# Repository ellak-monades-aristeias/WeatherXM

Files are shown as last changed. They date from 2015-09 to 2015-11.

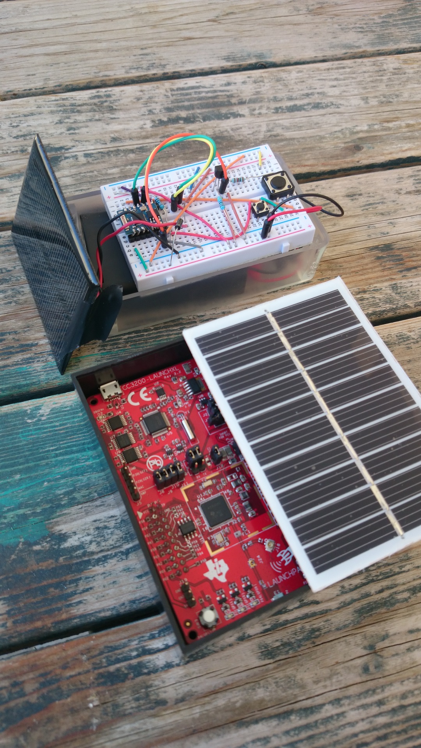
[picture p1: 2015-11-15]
D1-Evaluation/DSC_0020.JPG

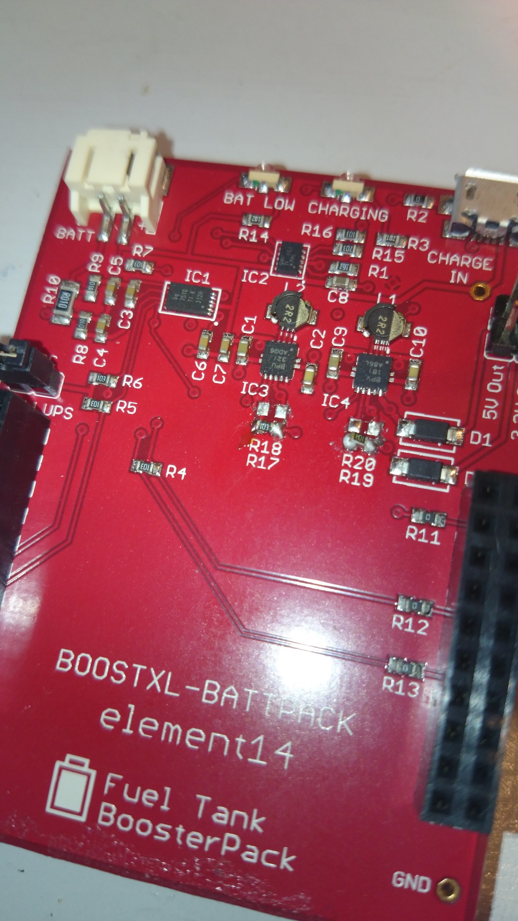
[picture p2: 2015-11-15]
D1-Evaluation/DSC_0005.JPG

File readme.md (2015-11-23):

## Weather ex Machina##

Στόχος του έργου είναι να κατασκευάσουμε ένα πρωτότυπο μετεωρολογικό σταθμό, ανταγωνιστικό προς τους υφιστάμενους ‘παραδοσιακούς’, μεγάλου κόστους μετεωρολογικούς σταθμούς. Ο σταθμός αυτός θα συμβάλλει στην υπέρβαση του προβλήματος διαθεσιμότητας μετεωρολογικών δεδομένων, μέσω της γεωγραφικής ανάπτυξης μεγάλου αριθμού αυτόνομων συνόλων αισθητήρων. Το υλισμικό θα είναι χαμηλού κόστους (<100€), με σύνδεση WiFi σε αστικό περιβάλλον και δυνατότητα για 2G/3G M2M για χρήση σε απομακρυσμένες περιοχές. Όλα τα δεδομένα θα συλλέγονται σε κεντρικό σύστημα σύννεφου (cloud) βασισμένο σε τεχνολογίες big data, ώστε να μπορεί να αποτελέσει μια πρώτη υποδομή για grassroot εφαρμογές smart-city.

**Ακολουθούν τα χαρακτηριστικά στα οποία στοχεύουμε:**
 - Συμπαγής, μικρού μεγέθους, εύκολης τοποθέτησης χωρίς απαραίτητη χρήση ιστού (π.χ. θα μπορούσε να κρέμεται σε ένα παράθυρο/μπαλκόνι/γωνία)
 - Mε αισθητήρες θερμοκρασίας, υγρασίας, ατμοσφαιρικής πίεσης, βροχής και αέρα. Για λόγους κόστους δε θα μετράμε βροχόπτωση, αλλά μόνο ύπαρξη βροχής με αισθητήρες σταγόνας. Αντίστοιχα δε θα μετράμε κατεύθυνση/ένταση αέρα αλλά από την κίνηση του ιδίου του σώματος του κουτιού, εφόσον κρέμεται από ένα κορδόνι, θα καταλαβαίνουμε την άπνοια ή ύπαρξη αέρα 
 - Aυτόνομο ενεργειακά, με την χρήση επαναφορτιζόμενων μπαταριών (LiPo or NiMH) που θα φορτίζουν από ένα μικρο ενσωματωμένο φωτοβολταικο
- Διασύνδεση WiFi και αποστολή δεδομένων μετρήσεων σε server μέσω (HTTP or MQTT)
 - Δυνατότητα ενημέρωσης firmware και φόρτιση μπαταρίας μέσω USB
 - Φιλικό προς DIY κατασκευαστές, συμβατό με Arduino  λογισμικό και έτοιμους αισθητήρες / modules / breakout boards
 - Δυνατότητα λειτουργίας από παραδοσιακό παραλληλεπίπεδο πλαστικό κουτί, μελέτη/προετοιμασία για περίβλημα/κουτί 3D εκτύπωσης, για οταν τα ηλεκτρονικά θα είναι σε custom PCB
 - Δυνατότητα over the Air firmware update
 - Δυνατότητα προσθήκης module για GPS/GALILEO, 3G with M2M Sim, Bluetooth
 - Δυνατότητα σύνδεσης εσωτερικής μονάδας με οθόνη για άμεση εμφάνιση των μετρήσεων

Πιο αναλυτικά οι εργασίες για αυτή την αρχική φάση του έργου είναι:

 **1. Αξιολόγηση υποψήφιου υλισμικού με υλοποίηση ελάχιστου συνδεδεμένου συστήματος (“hello IoT world” prototype)**
Έχουμε εντοπίσει αρκετές πλατφόρμες IoT με (σχεδόν) έτοιμα modules αισθητήρων, οι οποίες είναι συμβατές με arduino και φιλικές για prototyping. 

 - [TI CC3200](<https://github.com/ellak-monades-aristeias/WeatherXM/wiki/cc3200>)
 - [Spark/Particle Core](<https://github.com/ellak-monades-aristeias/WeatherXM/wiki/particle-core>)
 - [ESP8266 standalone](<https://github.com/ellak-monades-aristeias/WeatherXM/wiki/esp8266-standalone>)
 - [Atmega328 & NRF24 & ESP8266](<https://github.com/ellak-monades-aristeias/WeatherXM/wiki/ArduinoProMini_3.3.v-NRF24>)
 
Είναι εξαιρετικά δύσκολο να καταλήξει κανείς στην επιλογή μιας IoT πλατφόρμας χωρίς σε  βάθος προηγούμενη εμπειρία με τη συγκεκριμένη οικογένεια hardware/software. Οι εξελίξεις ομως στο IoT είναι τόσο ραγδαίες που πολλές πλατφόρμες πρώτο-εμφανίστηκαν στην αγορά μόλις πριν λίγους μήνες.  Για το λόγο αυτό και ακολουθώντας λογική agile, αναπτύσσουμε ένα ελάχιστο, αλλά ολοκληρωμένο σύστημα στις παραπάνω πλατφόρμες ώστε να τις αξιολογίσουμε. Το “hello IoT world” prototype είναι ένα wifi-θερμόμετρο με cloud backend (π.χ. thingspeak). Στόχος σε αυτή τη φάση είναι η αξιολόγηση και σύγκριση των πλεονεκτημάτων/μειονεκτημάτων της κάθε πλατφόρμας και η καταγραφή των διαφόρων αποτελεσμάτων (π.χ. κατανάλωση) ώστε να επιλέξουμε την ιδανικότερη με την ποια θα προχωρήσουμε. 

**2. Κατασκευή πρωτότυπου hardware**
Σε συνέχεια της αξιολόγησης και επιλογής ιδανικού hardawre, έχουμε προχωρήσουμε με την υλοποίηση των προδιαγραφών του μετεωρολογικού σταθμού, προσθέτοντας τα απαραίτητα περιφερειακά εξαρτήματα και αισθητήρες, πάνω στη βέλτιστη IoT πλατφόρμα (αποτέλεσμα προηγουμένης φάσης). Παράλληλα εμπλουτιζουμε το λογισμικό firmware  (arduino compatible) που θα διαχειρίζεται τα δεδομένα των αισθητήρων (μετεωρολογικά δεδομένα), και τα στέλνει περιοδικά σε κάποιο “ανοιχτό” cloud service  (π.χ. https://thingspeak.com/) 
([Περισσότερα](https://github.com/ellak-monades-aristeias/weatherxm/wiki/WxM-prototype))

**3. Σύνδεση hardware με backend ανοιχτό λογισμικό με δυνατότητα διαχείρισης big data**
Μέσα από προηγούμενες εμπειρίες έχουμε καταλήξει σε μια σειρά από προτεινόμενες τεχνολογίες για την διαχείριση big data όπως: Spring framework, Apache HBASE, Spark, mongoDB, Redis, Solr, etc.  οι οποίες όμως είναι αρκετά συνθέτες στη λειτουργία/εγκατάσταση. Στο opensource (CPAL-1.0) project [sitewhere.org](http://sitewhere.org) καθώς και στο [sentilo.io](http://sentilo.io) υπάρχει ήδη μια πολύ καλή διασύνδεση/integration αυτών των τεχνολογιών, καθώς και δυνατότητά για σύνδεση με arduino compatible hardware, οπότε θα κάνουμε τις απαραίτητες τροποποιήσεις στο firmware και στο server, ώστε να γίνει η σύνδεση του hardware μας με το backend για να μπορούμε να αξιοποιήσουμε τα μετεωρολογικά δεδομένα με διάφορους τρόπους, π.χ. απεικόνιση σε διαδραστικό χάρτη σε πραγματικό χρόνο, γραφήματα με ιστορικά δεδομένα, κτλ. Θα χρησιμοποιήσουμε MQTT ή HTTP πρωτόκολλο για να διευκολύνουμε και μελλοντικές διασυνδέσεις με τρίτα συστήματα ή/και άλλο IoT hardware με στόχο την δημιουργία υποδομής smart-city.
([Περισσότερα](https://github.com/ellak-monades-aristeias/WeatherXM/tree/master/D3-Backend))

**4. Μελέτη custom PCB και πρωτότυπου 3D printed πλαισίου (enclosure)**
Παράλληλα μελετάμε θέματα διάστασης/layout custom πλακέτας PCB για το hardware. Έχοντας τις τελικές διαστάσεις θα προχωρήσουμε στο σχεδιασμό custom 3d printed ABS plastic enclosure, που να μπορεί να φιλοξενήσει τους εξωτερικούς/εσωτερικούς αισθητήρες, το φωτοβολταϊκό, και τα υπόλοιπα ηλεκτρονικά, μπαταρίες κτλ.
([Περισσότερα](<https://github.com/ellak-monades-aristeias/WeatherXM/tree/master/D4-PCB-Enclosure>))

## Σε ποίους απευθύνεται - Κοινότητες Χρηστών - Προγραμματιστών(Developers) ##
To project στην παρούσα φάση του απευθύνεται σε DIY ΙοΤ & weather enthousiasts με γνώσεις hardware, electronics και embedded development, arduino. Μελλοντικές εκδόσεις θα είναι εφικτό να κατασκευαστούν απο λιγότερο τεχνικά έμπειρους χρήστες καθώς και να αποτελέσουν την βάση για (ανοιχτό) εμπορικό προϊόν χαμηλού κόστους.

## Κόστος ##
Το συνολικό κόστος του σταθμού είναι εξαιρετικά χαμηλό (λιγότερο από 100€) λαμβάνοντας υπόψιν οτι το κουτί μπορεί να εκτυπωθεί απο 3d printer. Υπάρχει μεγάλο περιθώριο περαιτέρω οικονομίας π.χ. ειδικά για τα ηλεκτρονικά εξαρτήματα αν κανείς τα προμηθευτεί  online απο κινα, μπορεί να φτάσει  ~20€. 

## Άδεια χρήσης ##
Τα παραδοτέα συμμορφώνονται με το Open Source Hardware Definition v1.0 με άδεια Creative Commons - Attribution - ShareAlike 3.0  για τα σχέδια/κυκλώματα. Ο κωδικάς ειναι Open Source Licensing GPL V2

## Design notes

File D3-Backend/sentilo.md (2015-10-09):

install java
install mvn

Installing Maven
Add a 3rd party PPA with Maven:
sudo add-apt-repository "deb http://ppa.launchpad.net/natecarlson/maven3/ubuntu precise main"
Update software packages with a new repository:
sudo apt-get update
Install Maven3:
sudo apt-get install maven3
Add a symlink so that the maven command is in the system path:
sudo ln -s /usr/share/maven3/bin/mvn /usr/bin/mvn

chmod +x

=======================================
Step 1: Compile and build platform code
=======================================
This command will compile and build platform code via Maven:

mvn clean install

Press enter when ready.

…..downloads dependencies….builds...tests…

Tests run: 38, Failures: 1, Errors: 0, Skipped: 0

[INFO] ------------------------------------------------------------------------
[INFO] Reactor Summary:
[INFO]
[INFO] sentilo-parent-pom ................................ SUCCESS [  2.984 s]
[INFO] sentilo-common .................................... SUCCESS [  8.227 s]
[INFO] sentilo-agent-common .............................. SUCCESS [  2.185 s]
[INFO] sentilo-platform .................................. SUCCESS [  0.007 s]
[INFO] sentilo-platform-common ........................... SUCCESS [  0.667 s]
[INFO] sentilo-platform-service .......................... SUCCESS [  3.189 s]
[INFO] sentilo-platform-server ........................... SUCCESS [  7.173 s]
[INFO] sentilo-platform-client-java ...................... SUCCESS [  2.261 s]
[INFO] sentilo-agent-alarm ............................... FAILURE [  1.808 s]
[INFO] sentilo-agent-relational .......................... SKIPPED
[INFO] sentilo-catalog-web ............................... SKIPPED
[INFO] sentilo-agent-location-updater .................... SKIPPED
[INFO] ------------------------------------------------------------------------
[INFO] BUILD FAILURE
[INFO] ------------------------------------------------------------------------
[INFO] Total time: 28.756 s
[INFO] Finished at: 2015-10-08T18:09:00-06:00
[INFO] Final Memory: 32M/205M
[INFO] ------------------------------------------------------------------------
[ERROR] Failed to execute goal org.apache.maven.plugins:maven-surefire-plugin:2.12.4:test (default-test) on project sentilo-agent-alert: There are test failures.
[ERROR]
[ERROR] Please refer to /opt/sentilo/sentilo-agent-alert/target/surefire-reports for the individual test results.
[ERROR] -> [Help 1]
[ERROR]
[ERROR] To see the full stack trace of the errors, re-run Maven with the -e switch.
[ERROR] Re-run Maven using the -X switch to enable full debug logging.
[ERROR]
[ERROR] For more information about the errors and possible solutions, please read the following articles:
[ERROR] [Help 1] http://cwiki.apache.org/confluence/display/MAVEN/MojoFailureException
[ERROR]
[ERROR] After correcting the problems, you can resume the build with the command
[ERROR]   mvn <goals> -rf :sentilo-agent-alert
Error code : 1

We are not going to use the agent-alarm (for now) so lets try skipping the tests
mvn install -Dmaven.test.skip=true

 cd sentilo-agent-location-updater/
cd sentilo-catalog-web/
cd sentilo-agent-relational/

need to install tomcat
sudo apt-get install tomcat7
sudo apt-get install tomcat7-admin

sudo nano /etc/tomcat7/tomcat-users.xml

<tomcat-users>
    <user username="admin" password="password" roles="manager-gui,admin-gui"/>
</tomcat-users>

sudo service tomcat7 restart

http://server_IP_address:8080
sudo add-apt-repository ppa:chris-lea/redis-server

 redis-cli ping
PONG

/etc/redis/redis.conf
chance requirepass foobar to sentilo

sudo service redis-server restart

http://docs.mongodb.org/manual/tutorial/install-mongodb-on-ubuntu/

enable authendication

mongo

> use admin
switched to db admin
> db.addUser( { user:"sentilo", pwd:"sentilo", roles: ["userAdminAnyDatabase"]})
WARNING: The 'addUser' shell helper is DEPRECATED. Please use 'createUser' instead
Successfully added user: { "user" : "sentilo", "roles" : [ "userAdminAnyDatabase" ] }

db.createUser ( { user:"sentilo", pwd:"sentilo", roles: ["userAdminAnyDatabase"]})

/etc/mongod.conf
auth=true

service mongod restart

root@oldserver:/opt/sentilo/scripts/mongodb# mongo -u sentilo -p sentilo sentilo init_data.js  --authenticationDatabase admin
MongoDB shell version: 2.6.11
connecting to: sentilo
Load applications
Load users
Load permissions

cp sentilo-catalog-web.war /usr/share/tomcat7-root/

sentilo-platform/sentilo-platform-server
mvn package appassembler:assemble -P dev

chmod +x

https://github.com/sentilo/sentilo/issues/33
apparently, it will not work with mongo 3!

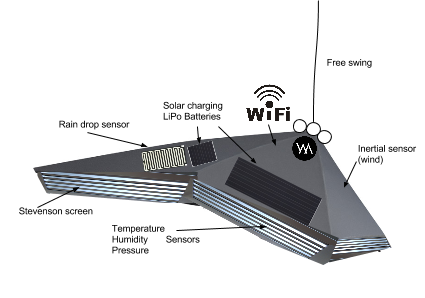
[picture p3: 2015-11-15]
wxm-diagram1.png

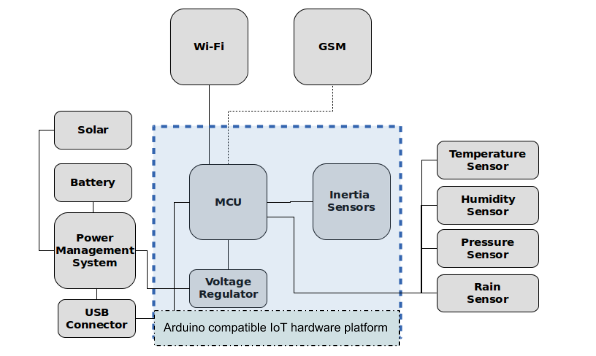
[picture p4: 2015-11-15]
wxm-diagram2.png

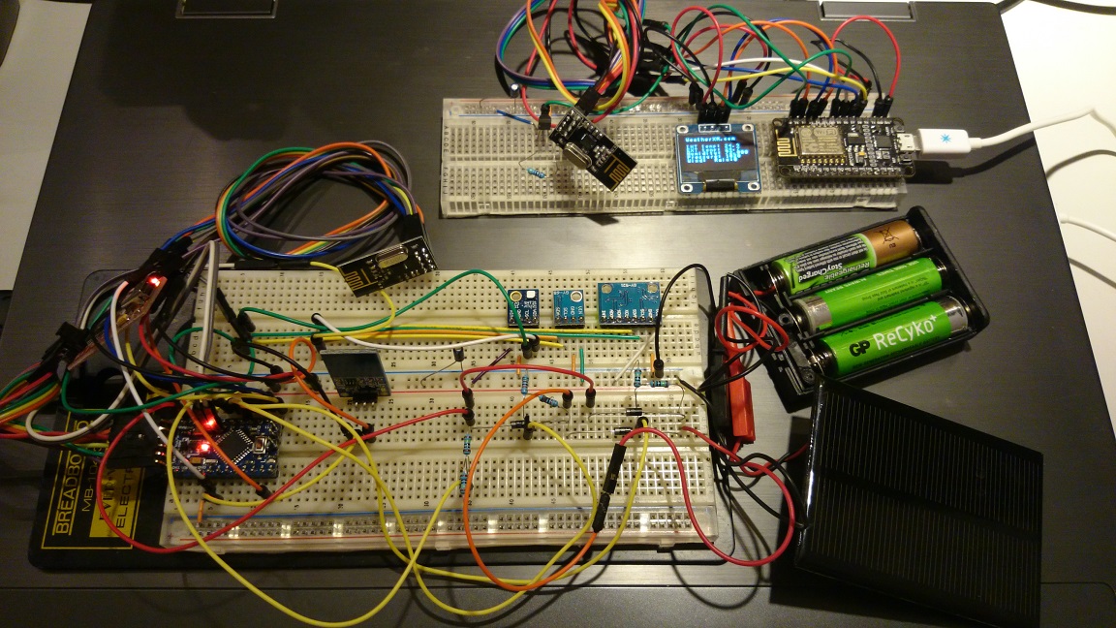
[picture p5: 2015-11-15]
D2-WeatherStation/DSC_0124b.jpg

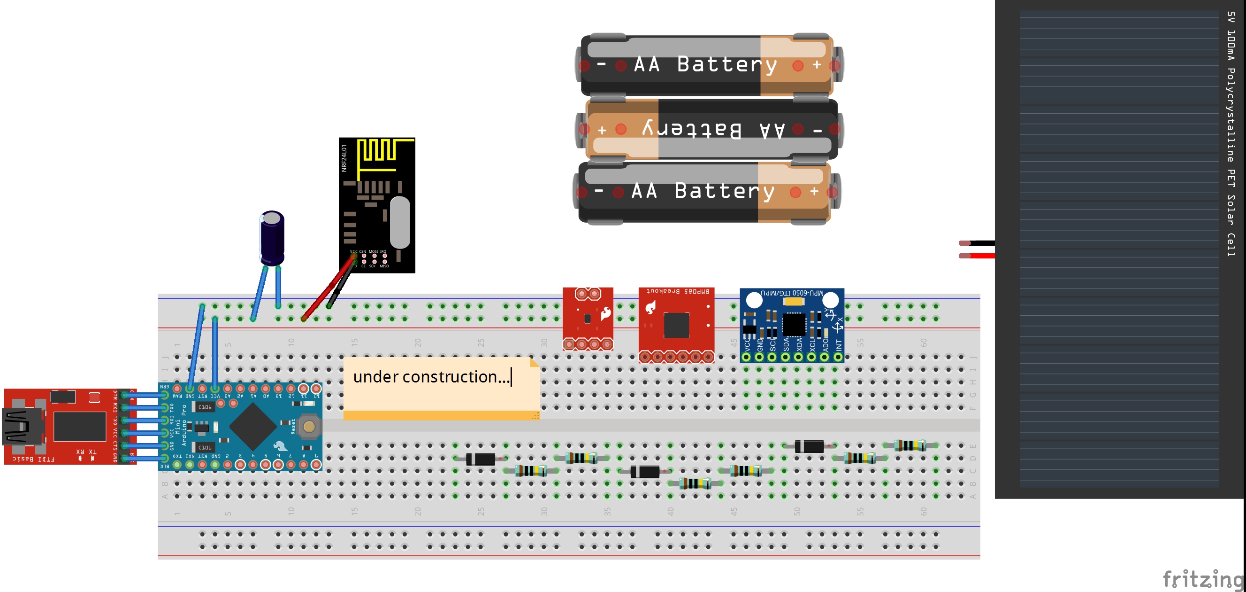
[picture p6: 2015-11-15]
D2-WeatherStation/WxM_INT_bb.jpg

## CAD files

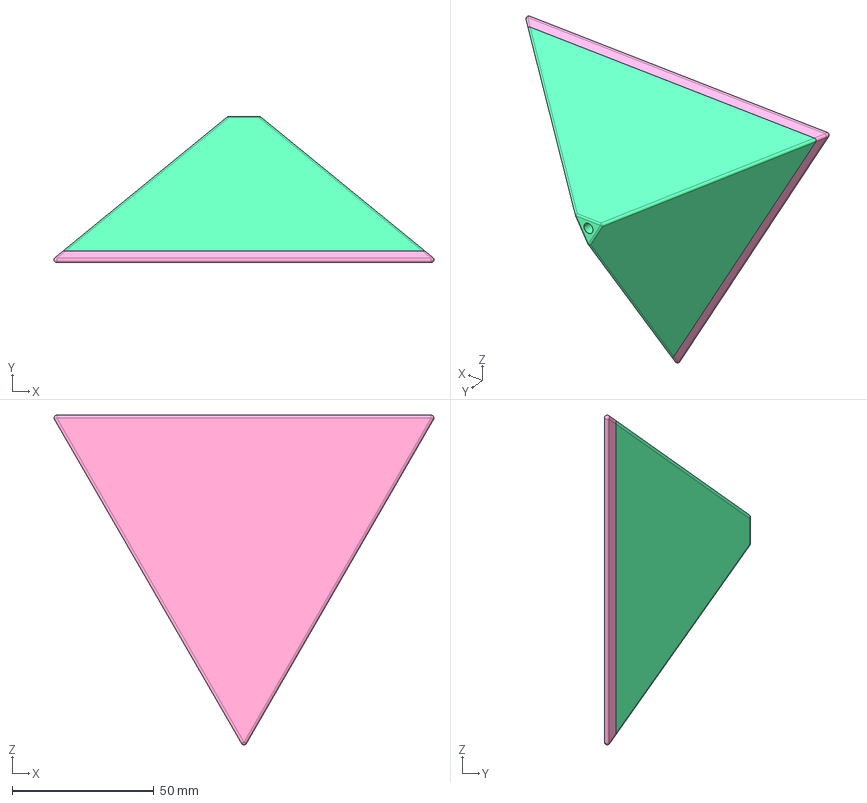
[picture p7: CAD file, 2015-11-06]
D4-PCB-Enclosure/wxm-enclosure.stp
133.9 x 51.5 x 116.2 mm
WXMACHINA_SKEL
WXMACHINA_BASE
WXMACHINA_COVER

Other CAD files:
D4-PCB-Enclosure/wxm-enclosure.stl

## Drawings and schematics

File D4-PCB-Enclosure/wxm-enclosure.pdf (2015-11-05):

2

B

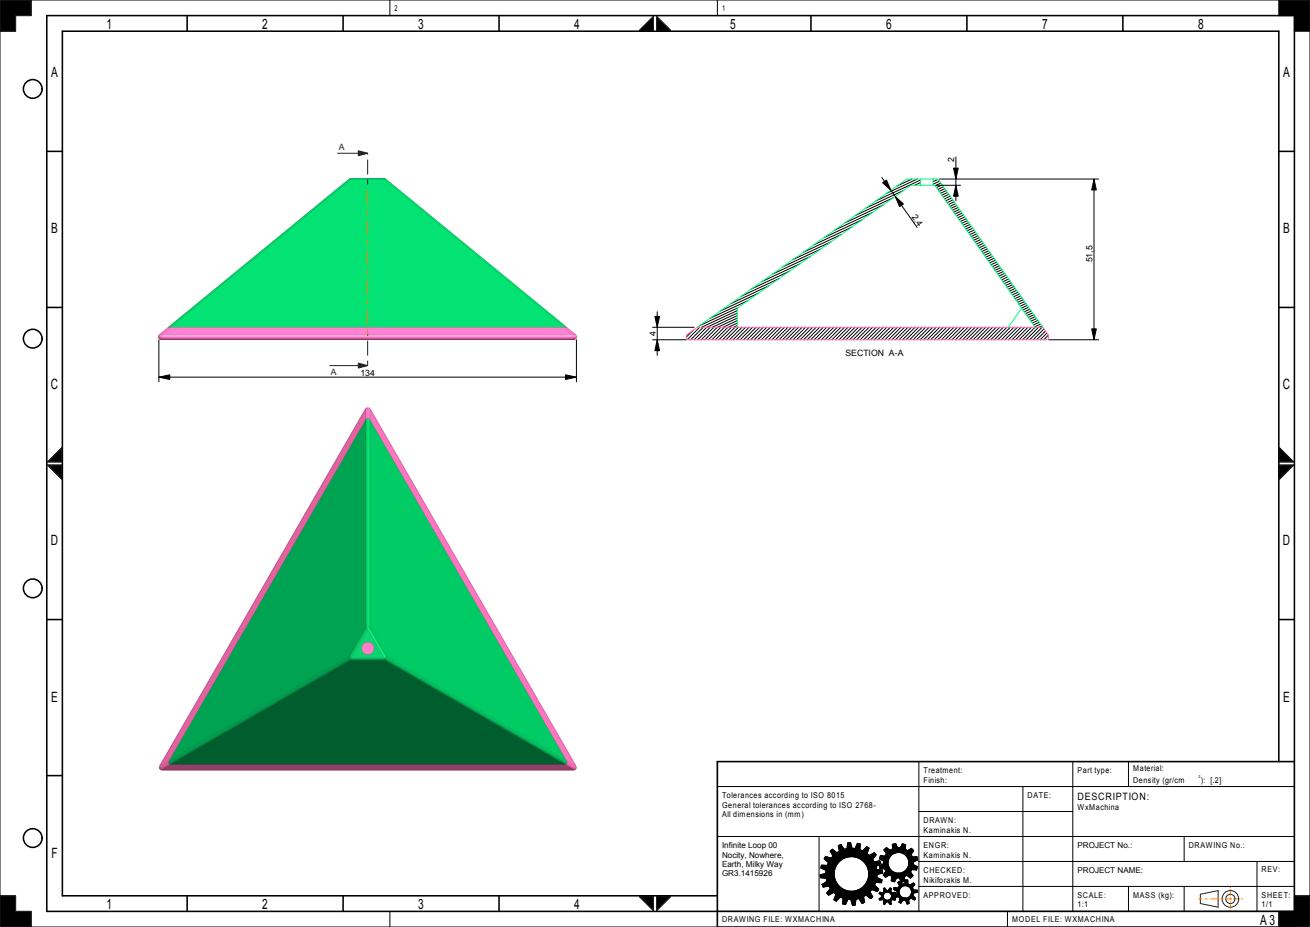
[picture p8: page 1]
DRAWING FILE: WXMACHINA; MODEL FILE: WXMACHINA; SECTION A-A

Treatment: Finish: | Part type: | Material: Density (gr/cm 3 ): [.2]

Tolerances according to ISO 8015 General tolerances according to ISO 2768-All dimensions in (mm) | | DATE: | DESCRIPTION: WxMachina

DRAWN: Kaminakis N.

Infinite Loop 00 Nocity, Nowhere, Earth, Milky Way GR3.1415926 | | ENGR: Kaminakis N. | | PROJECT No.: | DRAWING No.:

CHECKED: Nikiforakis M. | | PROJECT NAME: | REV:

APPROVED: | | SCALE: 1:1 | MASS (kg): | | | SHEET: 1/1

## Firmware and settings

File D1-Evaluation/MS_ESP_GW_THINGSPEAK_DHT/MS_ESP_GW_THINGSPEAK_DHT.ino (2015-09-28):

/**
 * The MySensors Arduino library handles the wireless radio link and protocol
 * between your home built sensors/actuators and HA controller of choice.
 * The sensors forms a self healing radio network with optional repeaters. Each
 * repeater and gateway builds a routing tables in EEPROM which keeps track of the
 * network topology allowing messages to be routed to nodes.
 *
 * Created by Henrik Ekblad <henrik.ekblad@mysensors.org>
 * Copyright (C) 2013-2015 Sensnology AB
 * Full contributor list: https://github.com/mysensors/Arduino/graphs/contributors
 *
 * Documentation: http://www.mysensors.org
 * Support Forum: http://forum.mysensors.org
 *
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
 *******************************
 *
 * REVISION HISTORY
 * Version 1.0 - Henrik EKblad
 * Contribution by a-lurker and Anticimex,
 * Contribution by Norbert Truchsess <norbert.truchsess@t-online.de>
 * Contribution by Ivo Pullens (ESP8266 support)
 * Contribution by Manolis Nikiforakis
 *
 * DESCRIPTION
 * The EthernetGateway sends data received from sensors to the WiFi link.
 * The gateway also accepts input on ethernet interface, which is then sent out to the radio network.
 *
 *  In addition, an OLED screen and a DHT11 are used, and sensor values can be directly forwarded to a cloud service (e.g. to Thingspeak) without using a controller.

 
 * VERA CONFIGURATION:
 * Enter "ip-number:port" in the ip-field of the Arduino GW device. This will temporarily override any serial configuration for the Vera plugin.
 * E.g. If you want to use the defualt values in this sketch enter: 192.168.178.66:5003
 *
 * LED purposes:
 * - To use the feature, uncomment WITH_LEDS_BLINKING in MyConfig.h
 * - RX (green) - blink fast on radio message recieved. In inclusion mode will blink fast only on presentation recieved
 * - TX (yellow) - blink fast on radio message transmitted. In inclusion mode will blink slowly
 * - ERR (red) - fast blink on error during transmission error or recieve crc error
 *
 * See http://www.mysensors.org/build/ethernet_gateway for wiring instructions.
 * The ESP8266 however requires different wiring:
 * nRF24L01+  ESP8266
 * VCC        VCC
 * CE         GPIO4
 * CSN/CS     GPIO15
 * SCK        GPIO14
 * MISO       GPIO12
 * MOSI       GPIO13
 *
 * Not all ESP8266 modules have all pins available on their external interface.
 * This code has been tested on NodeMCU dev kit v1.0 .
 * The ESP8266 requires a certain pin configuration to download code, and another one to run code:
 * - Connect OLED SCL to D4
 * - Connect OLED SDA to D3
 * - Connect DHT11 Data to D0
 * - nRF is connect as described in mysensors
 *
 * Hardware SHA204 signing is currently not supported!
 *
 * Make sure to fill in your ssid and WiFi password below for ssid & pass.
 */
#define NO_PORTB_PINCHANGES

#include <SPI.h>

#include <MySigningNone.h>
#include <MySigningAtsha204Soft.h>
#include <MyTransportNRF24.h>
#include <MyTransportRFM69.h>
#include <EEPROM.h>
#include <MyHwESP8266.h>
#include <ESP8266WiFi.h>

#include <MyParserSerial.h>
#include <MySensor.h>
#include <stdarg.h>
#include "GatewayUtil.h"

#include <Wire.h>
#include "font.h"
#include "f2s.h"

const char *ssid =  "";    // cannot be longer than 32 characters!
const char *pass =  ""; //

#define offset 0x00    // SDD1306                      // offset=0 for SSD1306 controller
#define OLED_address  0x3c                             // all the OLED's I have seen have this address

ADC_MODE(ADC_VCC);
const char* host = "api.thingspeak.com";
const char* thingspeak_key = "your key";

#include <DHT.h>
#define DHTTYPE DHT11
#define DHTPIN  16
DHT dht(DHTPIN, DHTTYPE);

#define INCLUSION_MODE_TIME 1 // Number of minutes inclusion mode is enabled
#define INCLUSION_MODE_PIN  5 // Digital pin used for inclusion mode button

#define RADIO_CE_PIN        4   // radio chip enable
#define RADIO_SPI_SS_PIN    15  // radio SPI serial select

#ifdef WITH_LEDS_BLINKING
#define RADIO_ERROR_LED_PIN 7  // Error led pin
#define RADIO_RX_LED_PIN    8  // Receive led pin
#define RADIO_TX_LED_PIN    9  // the PCB, on board LED
#endif


// NRFRF24L01 radio driver (set low transmit power by default)
MyTransportNRF24 transport(RADIO_CE_PIN, RADIO_SPI_SS_PIN, RF24_PA_LEVEL_GW);
//MyTransportRFM69 transport;


// Message signing driver (signer needed if MY_SIGNING_FEATURE is turned on in MyConfig.h)
#ifdef MY_SIGNING_FEATURE
MySigningNone signer;
//MySigningAtsha204Soft signer;
#endif

// Hardware profile
MyHwESP8266 hw;

// Construct MySensors library (signer needed if MY_SIGNING_FEATURE is turned on in MyConfig.h)
// To use LEDs blinking, uncomment WITH_LEDS_BLINKING in MyConfig.h
MySensor gw(transport, hw
#ifdef MY_SIGNING_FEATURE
            , signer
#endif
#ifdef WITH_LEDS_BLINKING
            , RADIO_RX_LED_PIN, RADIO_TX_LED_PIN, RADIO_ERROR_LED_PIN
#endif
           );


#define IP_PORT 5003         // The port you want to open 
#define MAX_SRV_CLIENTS 5    // how many clients should be able to telnet to this ESP8266

// a R/W server on the port
static WiFiServer server(IP_PORT);
static WiFiClient clients[MAX_SRV_CLIENTS];
static bool clientsConnected[MAX_SRV_CLIENTS];
static inputBuffer inputString[MAX_SRV_CLIENTS];

#define ARRAY_SIZE(x)  (sizeof(x)/sizeof(x[0]))


void output(const char *fmt, ... )
{
  char serialBuffer[MAX_SEND_LENGTH];
  va_list args;
  va_start (args, fmt );
  vsnprintf_P(serialBuffer, MAX_SEND_LENGTH, fmt, args);
  va_end (args);
  Serial.print(serialBuffer);
  for (uint8_t i = 0; i < ARRAY_SIZE(clients); i++)
  {
    if (clients[i] && clients[i].connected())
    {
      //       Serial.print("Client "); Serial.print(i); Serial.println(" write");
      clients[i].write((uint8_t*)serialBuffer, strlen(serialBuffer));
    }
  }
}

void setup()
{
  // Setup console
  hw_init();

  Serial.println(); Serial.println();
  Serial.println("ESP8266 MySensors Gateway");


  Wire.begin(0, 2);                             // Initialize I2C and OLED Display using PINs D3,D4 on NodeMCU
  init_OLED();                                    //
  reset_display();
  clear_display();
  sendStrXY("Hello WeatherXM", 0, 0);            // OLED first message
  sendStrXY("MySensors GW", 2, 0);

  //pinMode(DHTPIN, INPUT);
  dht.begin();


  // Reading temperature or humidity takes about 250 milliseconds!
  // Sensor readings may also be up to 2 seconds 'old' (its a very slow sensor)
  float h = dht.readHumidity();
  // Read temperature as Celsius (the default)
  float t = dht.readTemperature();
  // Read temperature as Fahrenheit (isFahrenheit = true)
  float f = dht.readTemperature(true);

  // Check if any reads failed and exit early (to try again).
  if (isnan(h) || isnan(t) || isnan(f)) {
    Serial.println("Failed to read from DHT sensor!");
  }

  // Compute heat index in Fahrenheit (the default)
  // float hif = dht.computeHeatIndex(f, h);
  
  // Compute heat index in Celsius (isFahreheit = false)
  float hic = dht.computeHeatIndex(t, h, false);

  Serial.print("Humidity: ");
  Serial.print(h);
  Serial.print(" %\t");
  Serial.print("Temperature: ");
  Serial.print(t);
  Serial.print(" *C ");
  //Serial.print(f);
  //Serial.print(" *F\t");
  Serial.print("Heat index: ");
  Serial.print(hic);
  Serial.print(" *C ");
  //Serial.print(hif);
  //Serial.println(" *F");

  Serial.print("Connecting to ");
  Serial.println(ssid);

  (void)WiFi.begin(ssid, pass);
  while (WiFi.status() != WL_CONNECTED)
  {
    delay(500);
    Serial.print(".");
  }
  Serial.println("WiFi Connected!");
  Serial.print("IP: "); Serial.println(WiFi.localIP());
  Serial.flush();

  setupGateway(INCLUSION_MODE_PIN, INCLUSION_MODE_TIME, output);

  // Initialize gateway at maximum PA level, channel 70 and callback for write operations
  gw.begin(incomingMessage, 0, true, 0);

  // start listening for clients
  server.begin();
  server.setNoDelay(true);

  clear_display();
  sendStrXY("   WeatherXM.com", 0, 0);            // OLED first message
  sendStrXY("EXT:", 2, 0); 
  sendStrXY("INT:", 4, 0);   
  sendStrXY("INTfeels:", 6, 0);   
  char buffer[25];
  sendStrXY( floatToString(buffer,t,1), 4, 4);   
  sendStrXY( floatToString(buffer,h,0), 4, 10);   
  sendStrXY( floatToString(buffer,hic,1), 6, 10);   

}


void loop() {
  gw.process();
  checkButtonTriggeredInclusion();
  checkInclusionFinished();

  // Go over list of clients and stop any that are no longer connected.
  // If the server has a new client connection it will be assigned to a free slot.
  bool allSlotsOccupied = true;
  for (uint8_t i = 0; i < ARRAY_SIZE(clients); i++)
  {
    if (!clients[i].connected())
    {
      if (clientsConnected[i])
      {
        Serial.print("Client "); Serial.print(i); Serial.println(" disconnected");
        clients[i].stop();
      }
      //check if there are any new clients
      if (server.hasClient())
      {
        clients[i] = server.available();
        inputString[i].idx = 0;
        Serial.print("Client "); Serial.print(i); Serial.println(" connected");
        output(PSTR("0;0;%d;0;%d;Gateway startup complete.\n"),  C_INTERNAL, I_GATEWAY_READY);
      }
    }
    bool connected = clients[i].connected();
    clientsConnected[i] = connected;
    allSlotsOccupied &= connected;
  }
  if (allSlotsOccupied && server.hasClient())
  {
    //no free/disconnected spot so reject
    Serial.println("No free slot available");
    WiFiClient c = server.available();
    c.stop();
  }

  // Loop over clients connect and read available data
  for (uint8_t i = 0; i < ARRAY_SIZE(clients); i++)
  {
    while (clients[i].connected() && clients[i].available())
    {
      char inChar = clients[i].read();
      if ( inputString[i].idx < MAX_RECEIVE_LENGTH - 1 )
      {
        // if newline then command is complete
        if (inChar == '\n')
        {
          // a command was issued by the client
          // we will now try to send it to the actuator
          inputString[i].string[inputString[i].idx] = 0;

          // echo the string to the serial port
          Serial.print("Client "); Serial.print(i); Serial.print(": "); Serial.println(inputString[i].string);

          parseAndSend(gw, inputString[i].string);

          // clear the string:
          inputString[i].idx = 0;
          // Finished with this client's message. Next loop() we'll see if there's more to read.
          break;
        } else {
          // add it to the inputString:
          inputString[i].string[inputString[i].idx++] = inChar;
        }
      } else {
        // Incoming message too long. Throw away
        Serial.print("Client "); Serial.print(i); Serial.println(": Message too long");
        inputString[i].idx = 0;
        // Finished with this client's message. Next loop() we'll see if there's more to read.
        break;
      }
    }
  }





  float h = dht.readHumidity();
  float t = dht.readTemperature();
  // Check if any reads failed and exit early (to try again).
  if (isnan(h) || isnan(t)  ) {
    Serial.println("Failed to read from DHT sensor!");
  } else {
  float hic = dht.computeHeatIndex(t, h, false);
  char buffer[25];
  sendStrXY( floatToString(buffer,t,1), 4, 4);   
  sendStrXY( floatToString(buffer,h,0), 4, 10);   
  sendStrXY( floatToString(buffer,hic,1), 6, 10);  
  }

  
}


void incomingMessage(const MyMessage &message) {

  Serial.print("Sensor:");
  serial(PSTR("%d;%d;%d;%d;%d;%s\n"), message.sender, message.sensor, mGetCommand(message), mGetAck(message), message.type, message.getString(convBuf));

  if (message.type == V_TEMP) {
    sendStrXY(message.getString(convBuf), 2,4);
    thingspeak(message.getString(convBuf));
  }

}


//--------------- OLED FUNCTIONS ------------------

//==========================================================//
// Resets display depending on the actual mode.
static void reset_display(void)
{
  displayOff();
  clear_display();
  displayOn();
}

//==========================================================//
// Turns display on.
void displayOn(void)
{
  sendcommand(0xaf);        //display on
}

//==========================================================//
// Turns display off.
void displayOff(void)
{
  sendcommand(0xae);    //display off
}

//==========================================================//
// Clears the display by sendind 0 to all the screen map.
static void clear_display(void)
{
  unsigned char i, k;
  for (k = 0; k < 8; k++)
  {
    setXY(k, 0);
    {
      for (i = 0; i < (128 + 2 * offset); i++) //locate all COL
      {
        SendChar(0);         //clear all COL
        //delay(10);
      }
    }
  }
}

//==========================================================//
// Actually this sends a byte, not a char to draw in the display.
// Display's chars uses 8 byte font the small ones and 96 bytes
// for the big number font.
static void SendChar(unsigned char data)
{
  //if (interrupt && !doing_menu) return;   // Stop printing only if interrupt is call but not in button functions

  Wire.beginTransmission(OLED_address); // begin transmitting
  Wire.write(0x40);//data mode
  Wire.write(data);
  Wire.endTransmission();    // stop transmitting
}

//==========================================================//
// Prints a display char (not just a byte) in coordinates X Y,
// being multiples of 8. This means we have 16 COLS (0-15)
// and 8 ROWS (0-7).
static void sendCharXY(unsigned char data, int X, int Y)
{
  setXY(X, Y);
  Wire.beginTransmission(OLED_address); // begin transmitting
  Wire.write(0x40);//data mode

  for (int i = 0; i < 8; i++)
    Wire.write(pgm_read_byte(myFont[data - 0x20] + i));

  Wire.endTransmission();    // stop transmitting
}

//==========================================================//
// Used to send commands to the display.
static void sendcommand(unsigned char com)
{
  Wire.beginTransmission(OLED_address);     //begin transmitting
  Wire.write(0x80);                          //command mode
  Wire.write(com);
  Wire.endTransmission();                    // stop transmitting
}

//==========================================================//
// Set the cursor position in a 16 COL * 8 ROW map.
static void setXY(unsigned char row, unsigned char col)
{
  sendcommand(0xb0 + row);              //set page address
  sendcommand(offset + (8 * col & 0x0f)); //set low col address
  sendcommand(0x10 + ((8 * col >> 4) & 0x0f)); //set high col address
}


//==========================================================//
// Prints a string regardless the cursor position.
static void sendStr(unsigned char *string)
{
  unsigned char i = 0;
  while (*string)
  {
    for (i = 0; i < 8; i++)
    {
      SendChar(pgm_read_byte(myFont[*string - 0x20] + i));
    }
    *string++;
  }
}

//==========================================================//
// Prints a string in coordinates X Y, being multiples of 8.
// This means we have 16 COLS (0-15) and 8 ROWS (0-7).
static void sendStrXY( char *string, int X, int Y)
{
  setXY(X, Y);
  unsigned char i = 0;
  while (*string)
  {
    for (i = 0; i < 8; i++)
    {
      SendChar(pgm_read_byte(myFont[*string - 0x20] + i));
    }
    *string++;
  }
}


//==========================================================//
// Inits oled and draws logo at startup
static void init_OLED(void)
{
  sendcommand(0xae);    //display off
  sendcommand(0xa6);            //Set Normal Display (default)
  // Adafruit Init sequence for 128x64 OLED module
  sendcommand(0xAE);             //DISPLAYOFF
  sendcommand(0xD5);            //SETDISPLAYCLOCKDIV
  sendcommand(0x80);            // the suggested ratio 0x80
  sendcommand(0xA8);            //SSD1306_SETMULTIPLEX
  sendcommand(0x3F);
  sendcommand(0xD3);            //SETDISPLAYOFFSET
  sendcommand(0x0);             //no offset
  sendcommand(0x40 | 0x0);      //SETSTARTLINE
  sendcommand(0x8D);            //CHARGEPUMP
  sendcommand(0x14);
  sendcommand(0x20);             //MEMORYMODE
  sendcommand(0x00);             //0x0 act like ks0108

  //sendcommand(0xA0 | 0x1);      //SEGREMAP   //Rotate screen 180 deg
  sendcommand(0xA0);

  //sendcommand(0xC8);            //COMSCANDEC  Rotate screen 180 Deg
  sendcommand(0xC0);

  sendcommand(0xDA);            //0xDA
  sendcommand(0x12);           //COMSCANDEC
  sendcommand(0x81);           //SETCONTRAS
  sendcommand(0xCF);           //
  sendcommand(0xd9);          //SETPRECHARGE
  sendcommand(0xF1);
  sendcommand(0xDB);        //SETVCOMDETECT
  sendcommand(0x40);
  sendcommand(0xA4);        //DISPLAYALLON_RESUME
  sendcommand(0xA6);        //NORMALDISPLAY

  clear_display();
  sendcommand(0x2e);            // stop scroll
  //----------------------------REVERSE comments----------------------------//
  sendcommand(0xa0);    //seg re-map 0->127(default)
  sendcommand(0xa1);    //seg re-map 127->0
  sendcommand(0xc8);
  delay(1000);
  //----------------------------REVERSE comments----------------------------//
  // sendcommand(0xa7);  //Set Inverse Display
  // sendcommand(0xae);   //display off
  sendcommand(0x20);            //Set Memory Addressing Mode
  sendcommand(0x00);            //Set Memory Addressing Mode ab Horizontal addressing mode
  //  sendcommand(0x02);         // Set Memory Addressing Mode ab Page addressing mode(RESET)
}














//-------------- ThingSpeak -----------------------------

void thingspeak( String Dtemp) {

  Serial.print("connecting to ");
  Serial.println(host);

  // Use WiFiClient class to create TCP connections
  WiFiClient client;
  const int httpPort = 80;
  if (!client.connect(host, httpPort)) {
    Serial.println("connection failed");
    return;
  }


  String voltage = String( ESP.getVcc());
  String url = "/update?key=";
  url += thingspeak_key;
  url += "&field1=";
  url += String(Dtemp);
  url += "&field2=";
  url += voltage;

  Serial.print("Requesting URL: ");
  Serial.println(url);

  // This will send the request to the server
  client.print(String("GET ") + url + " HTTP/1.1\r\n" +
               "Host: " + host + "\r\n" +
               "Connection: close\r\n\r\n");
  delay(10);

  // Read all the lines of the reply from server and print them to Serial
  while (client.available()) {
    String line = client.readStringUntil('\r');
    Serial.print(line);
  }
}

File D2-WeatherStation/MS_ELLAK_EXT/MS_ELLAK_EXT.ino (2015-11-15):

/**
 * The MySensors Arduino library handles the wireless radio link and protocol
 * between your home built sensors/actuators and HA controller of choice.
 * The sensors forms a self healing radio network with optional repeaters. Each
 * repeater and gateway builds a routing tables in EEPROM which keeps track of the
 * network topology allowing messages to be routed to nodes.
 *
 * Created by Henrik Ekblad <henrik.ekblad@mysensors.org>
 * Copyright (C) 2013-2015 Sensnology AB
 * Full contributor list: https://github.com/mysensors/Arduino/graphs/contributors
 *
 * Documentation: http://www.mysensors.org
 * Support Forum: http://forum.mysensors.org
 *
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
 *******************************
 *
 *
 * DESCRIPTION
 * Early attempts for a weather station which utilizes the mysensors.org framework
 * uses inertial sensors for wind detection, and capacitive for rain
 * by Manolis Nikiforakis - WeatherXM.com
 */

#include <SPI.h>
#include <MySensor.h>
#include <Wire.h>
#include <Adafruit_BMP085.h>
#include <SI7021.h>

#define MY_NODE_ID 1

#define BARO_CHILD 0
#define TEMP_CHILD 1
#define TEMP_CHILD2 2
#define HUM_CHILD 3
#define RAIN_CHILD 4
#define VOLT1_CHILD 5
#define VOLT2_CHILD 6
#define VOLT3_CHILD 7

#define DIGITAL_INPUT_RAIN_SENSOR 3   // Digital input for capacitive/rain sensor. 
#define V1_SENSE_PIN 0
#define V2_SENSE_PIN 1
#define V3_SENSE_PIN 2

const float ALTITUDE = 35; // Athens, Greece = 25m <-- adapt this value to your own location's altitude.

// Sleep time between reads (in seconds). Do not change this value as the forecast algorithm needs a sample every minute.
const unsigned long SLEEP_TIME = 3000;

Adafruit_BMP085 bmp = Adafruit_BMP085();      // Digital Pressure Sensor
SI7021 si;
MySensor gw;


boolean metric;
MyMessage tempMsg(TEMP_CHILD, V_TEMP);
MyMessage pressureMsg(BARO_CHILD, V_PRESSURE);
MyMessage temp2Msg(TEMP_CHILD2, V_TEMP);
MyMessage humMsg(HUM_CHILD, V_HUM);
MyMessage rainMsg(RAIN_CHILD, V_RAINRATE);
MyMessage v1Msg(VOLT1_CHILD, V_VAR1);
MyMessage v2Msg(VOLT2_CHILD, V_VAR2);
MyMessage v3Msg(VOLT3_CHILD, V_VAR3);
void setup()
{
  gw.begin();
  // Send the sketch version information to the gateway and Controller
  gw.sendSketchInfo("WeatherXM external unit", "1.1");
  pinMode(DIGITAL_INPUT_RAIN_SENSOR, INPUT);
  metric = gw.getConfig().isMetric;

  if (!bmp.begin())  {
    Serial.println("Could not find a valid BMP085 sensor, check wiring!");
    while (1) {}
  }


  if (!si.begin())  {
    Serial.println("Could not find a valid SI7021 sensor, check wiring!");
    while (1) {}
  }


  // Register sensors to gw (they will be created as child devices)
  gw.present(BARO_CHILD, S_BARO);
  gw.present(TEMP_CHILD, S_TEMP);
  gw.present(TEMP_CHILD2, S_TEMP);
  gw.present(HUM_CHILD, S_HUM);
  gw.present(RAIN_CHILD, S_RAIN);
  gw.present(VOLT1_CHILD, S_MULTIMETER);
  gw.present(VOLT2_CHILD, S_MULTIMETER);
  gw.present(VOLT3_CHILD, S_MULTIMETER);
}

void loop()
{
  float pressure = bmp.readSealevelPressure(ALTITUDE) / 100.0;
  //float pressure = bmp.readPressure()/100;
  float temperature = bmp.readTemperature();

  si7021_env sidata = si.getHumidityAndTemperature();
  float temp2 = sidata.celsiusHundredths / 100;
  int hum =  sidata.humidityPercent ;

  Serial.print("Temperature2 = ");
  Serial.print(temp2);
  Serial.println(metric ? " *C" : " *F");
  //gw.send(temp2Msg.set(temp2, TEMP_CHILD2));

  Serial.print("Humidity = ");
  Serial.println(hum);
  gw.send(humMsg.set(hum, HUM_CHILD));

  if (!metric)  {
    // Convert to fahrenheit
    temperature = temperature * 9.0 / 5.0 + 32.0;
  }

  Serial.print("Temperature = ");
  Serial.print(temperature);
  Serial.println(metric ? " *C" : " *F");
  gw.send(tempMsg.set(temperature, TEMP_CHILD));

  Serial.print("Pressure = ");
  Serial.print(pressure);
  Serial.println(" hPa");
  gw.send(pressureMsg.set(pressure, BARO_CHILD));

  int rainValue = digitalRead(DIGITAL_INPUT_RAIN_SENSOR);
  Serial.print("Rain = ");
  Serial.println(rainValue);
  gw.send(rainMsg.set((byte)rainValue));

  // get the battery Voltage
  int v1 = analogRead(V1_SENSE_PIN);
  Serial.print("Volt1 = ");
  Serial.println(v1*2*3.3/1023);
  gw.send(v1Msg.set( v1*2*3.3/1000 , VOLT1_CHILD));

  int v2 = analogRead(V2_SENSE_PIN);
  Serial.print("Volt2 = ");
  Serial.println(v2*2*3.3/1023);
  gw.send(v2Msg.set( v2*2*3.3/1023 , VOLT2_CHILD));

  int v3 = analogRead(V3_SENSE_PIN);
  Serial.print("Volt3 = ");
  Serial.println(v3*2*3.3/1023);
  gw.send(v3Msg.set( v3*2*3.3/1023 , VOLT3_CHILD));

  //gw.sendBatteryLevel(sensorValue);


  gw.sleep(SLEEP_TIME);

}

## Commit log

2015-11-06 early 3d models
    [wxm-enclosure.stl, wxm-enclosure.stp]
2015-11-13 working: -OLED -communications (NRF24 & ThingSpeak) -external/internal temp -humidity -pressure
    Pending wind, vcc
2015-11-15 added rain sensors solar and bat voltage monitoring
2015-11-15 photos, schematics, fritzing parts
    [WxM_INT.fzz]

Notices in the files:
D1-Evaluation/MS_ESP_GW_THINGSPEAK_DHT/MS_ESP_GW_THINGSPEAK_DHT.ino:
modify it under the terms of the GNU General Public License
